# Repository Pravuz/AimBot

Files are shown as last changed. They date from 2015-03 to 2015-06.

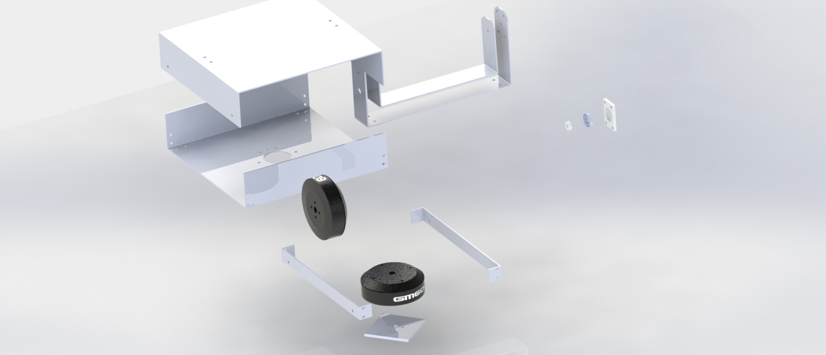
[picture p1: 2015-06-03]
3D model/Rendered images/Overview parts.JPG

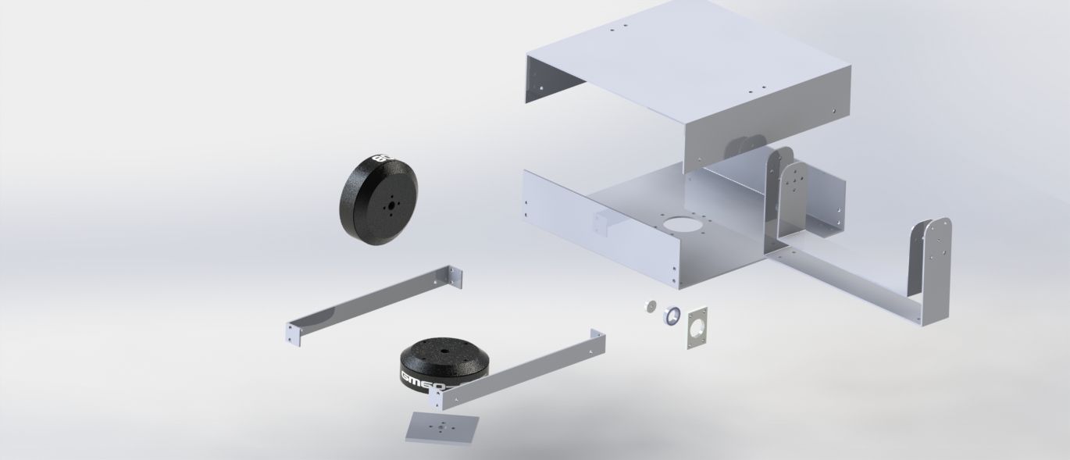
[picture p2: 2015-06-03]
3D model/Rendered images/Overview parts 2.JPG

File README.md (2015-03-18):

# AimBot
<i>Undergrad Robotics project. Check out our youtube (www.youtube.com/channel/UCTwyZwKfavoUkVI_xjq9n3A) if you're interested.
This is a Bachelors project on constructing an automated camera-rig.</i><br /><br />

<h2>Folder contents:</h2>

<h3>Arduino:</h3> Arduino mega 2560, the "brain" of the rig <br />
<h3>Brugi:</h3> Brushless DC-motor controller, based on Sine-wave pwm on 2-axis. <br />
<h3>Common:</h3> Files that all source code implements. protocols etc.<br />
<h3>Desktop:</h3> Windows configuration program <br />
<h3>Pixy:</h3> Camera module with a dual-core arm cpu for image processing.<br />
<h3>Release:</h3> Executable's etc for end-user.<br />

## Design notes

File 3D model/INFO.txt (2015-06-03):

INFO:
-------------------------
This folder contains 3D models created in SolidWorks, as well as
rendered images.

Folders:
-------------------------
- 'Assembly 13 - 2 axis' 
	Contains the 3D model of the 2axis-rig
	The full assembly is located at: 
		'/3D model/Assembly 13 - 2 axis/Assembly/Assem2.SLDASM'

- 'Assembly 14 - 3 axis' 
	Contains the 3D model of the 3axis-rig
	The full assembly is located at: 
		'/3D model/Assembly 14 - 3 axis/Assembly/Assem2.SLDASM'

- 'Rendered images'
	Contains rendered images

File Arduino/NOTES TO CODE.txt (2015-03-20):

--------timepassed and oldtime --------------------------------
// max value for 16bit int = 32767
// 32 767us = 0,032767s og 1/0,032767s=30,51850947599719hz
// max value for 16bit uint = 65535
// could change timepassed to a 16bit uint
// oldtime however gets huge, needs long

--------interrupts  --------------------------------
// Interrupt pins on mega:
// int.0 = 2, int.1 = 3, int.2 = 21, int.3 = 20, int.4 = 19, int.5 = 18

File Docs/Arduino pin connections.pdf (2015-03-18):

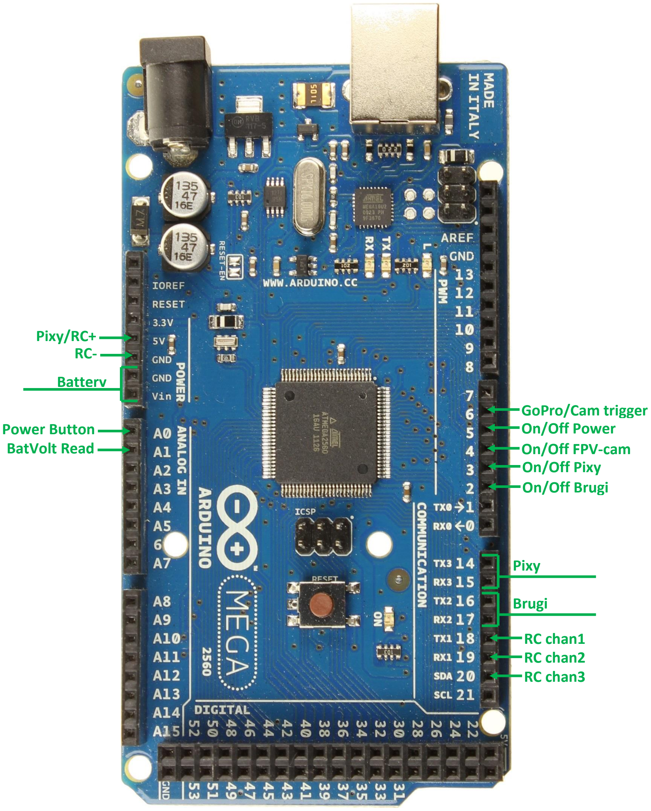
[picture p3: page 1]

Pixy

Brugi

BatVolt Read

Power

Button

RC chan1
RC chan2
RC chan3

On/Off Pixy

On/Off FPV

-cam

On/Off Brugi

On/Off Power

Battery

Pixy/RC+
RC

GoPro/Cam trigger

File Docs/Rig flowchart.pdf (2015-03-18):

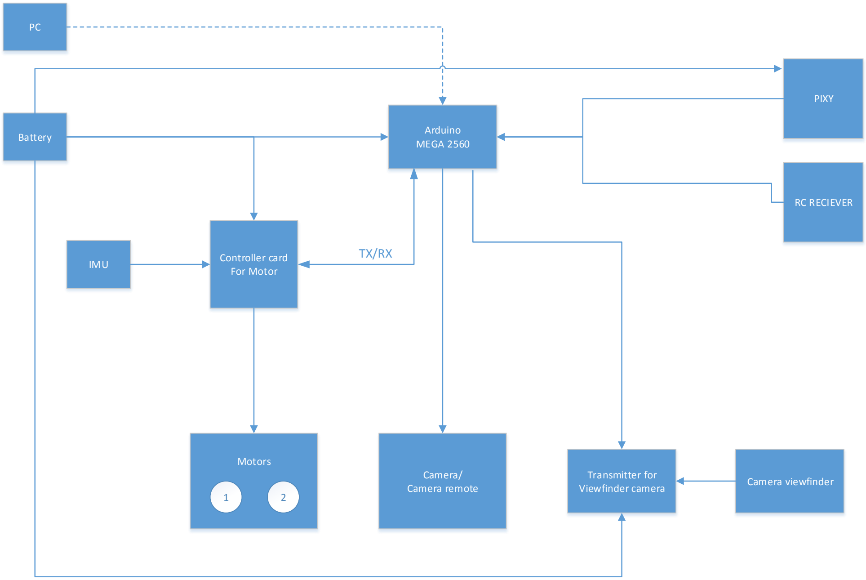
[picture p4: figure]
Arduino MEGA 2560; PIXY; RC RECIEVER; Battery; Controller card For Motor IMU; Transmitter for; Viewfinder camera; Camera viewfinder; Motors; Camera/ Camera remote

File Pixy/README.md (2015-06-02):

<h1>Pixy</h1>
</br>
<b>Q:</b> Where does the magic happen?</br>
<b>A:</b> In the GreyShades class (pixy/gcc/video/proggreyshades.h\cpp)</br>
</br>
<b>Q:</b> How does it work?</br>
<b>A:</b> GreyShades attempts to identify moving objects by tracking changes in individual pixel values (luminosity). </br>Because of certain limitations, the filtering of objects is quite rough however. </br>
</br>
<b>Q:</b> Why is it called greyshades?</br>
<b>A:</b> Because it's not based on colors, but shades of grey ( sizeOf(uint8_t)-1 different shades in fact).</br>
</br>
<b>Q:</b> What else can this firmware do?</br>
<b>A:</b> Not much. This firmware is based on an early pre-alpha gcc build by CharmedLabs, stripped down to rule out potential </br>crashes/resource usage/bugs.</br>
</br>
<b>Q:</b> Will this firmware work on my Pixy?</br>
<b>A:</b> Maybe, I'm not certain Pixymon will allow flashing your pixy with the .hex generated by this code. I used a</br> debugger (LPC-Link2) to test and upload the firmware. </br>
</br>
<b>Q:</b> Is this currently a work in progress?</br>
<b>A:</b> This project was part of a bachelor's project, which is now finished. The source code found here will remain as is, </br>with no guarantee or promises with it. </br>
</br>
<b>Q:</b> Can I use your code as I please?</br>
<b>A:</b> Yes, by all means! Some credit would be nice however :)</br>
</br>
<b>Q:</b> Can I contact you?</br>
<b>A:</b> Yes, preferably via github (I'm Pravuz). I'm not promising any reply, as I'm quite busy nowadays. </br>
</br></br></br>
- Pravuz

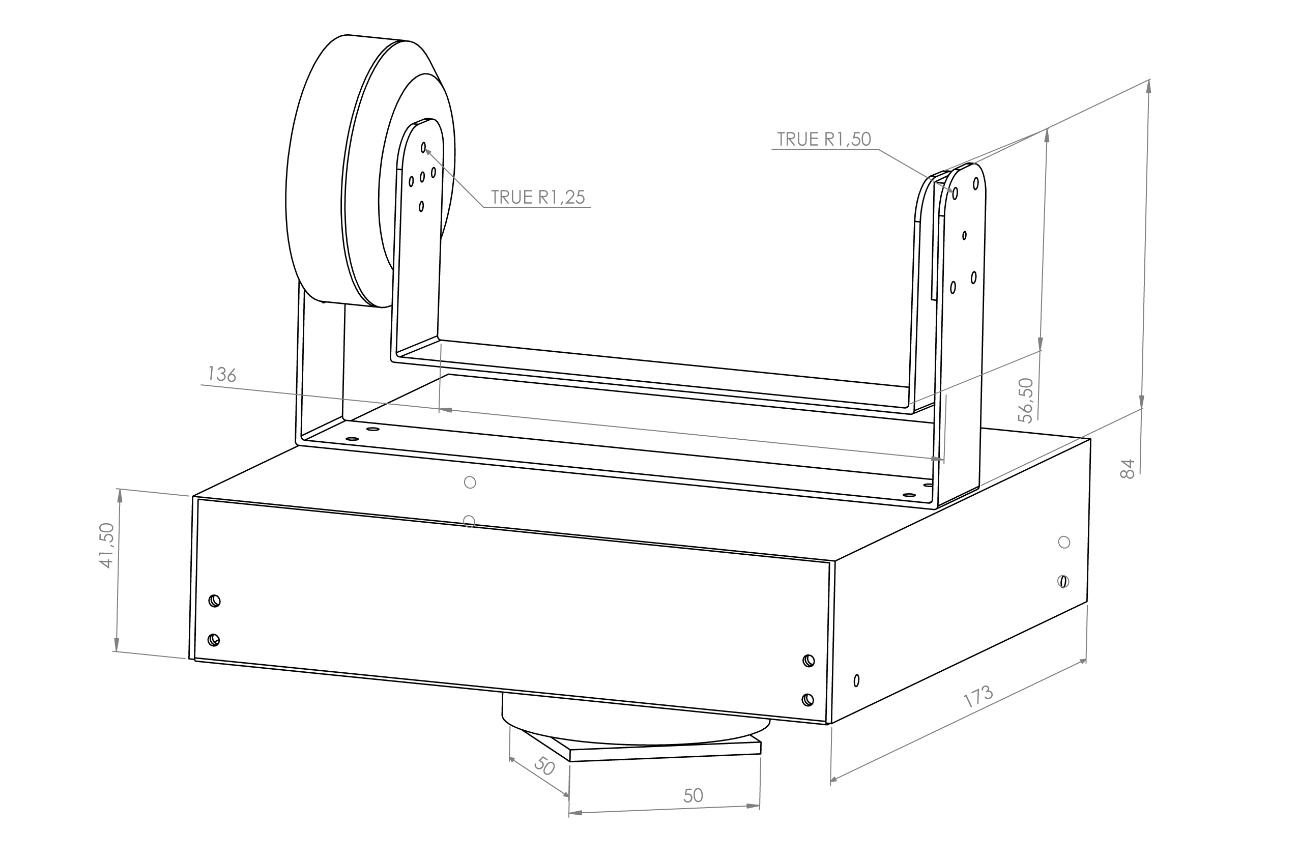
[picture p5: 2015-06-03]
3D model/Rendered images/Schematic view.PNG

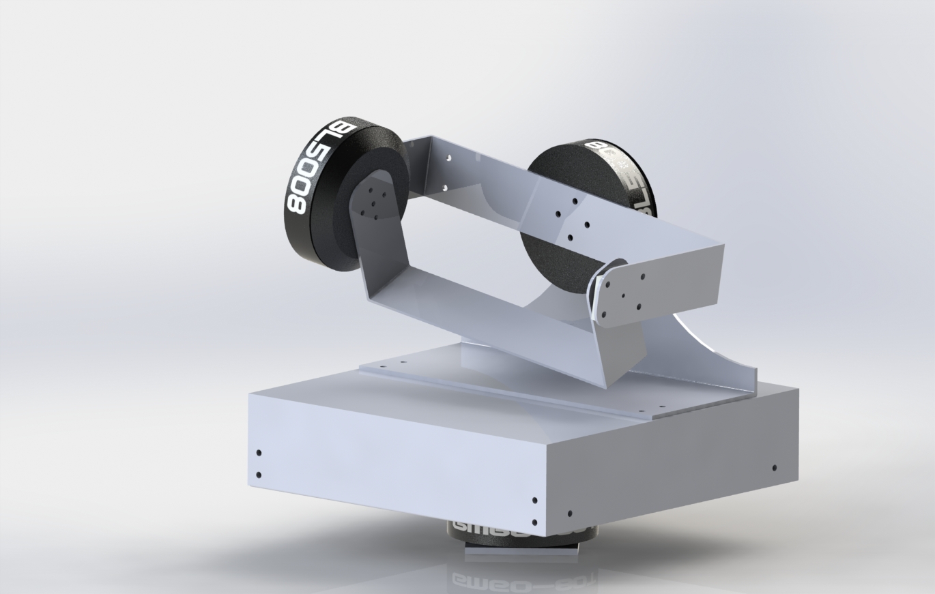
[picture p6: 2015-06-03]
3D model/Rendered images/Front view 3rd axis.JPG

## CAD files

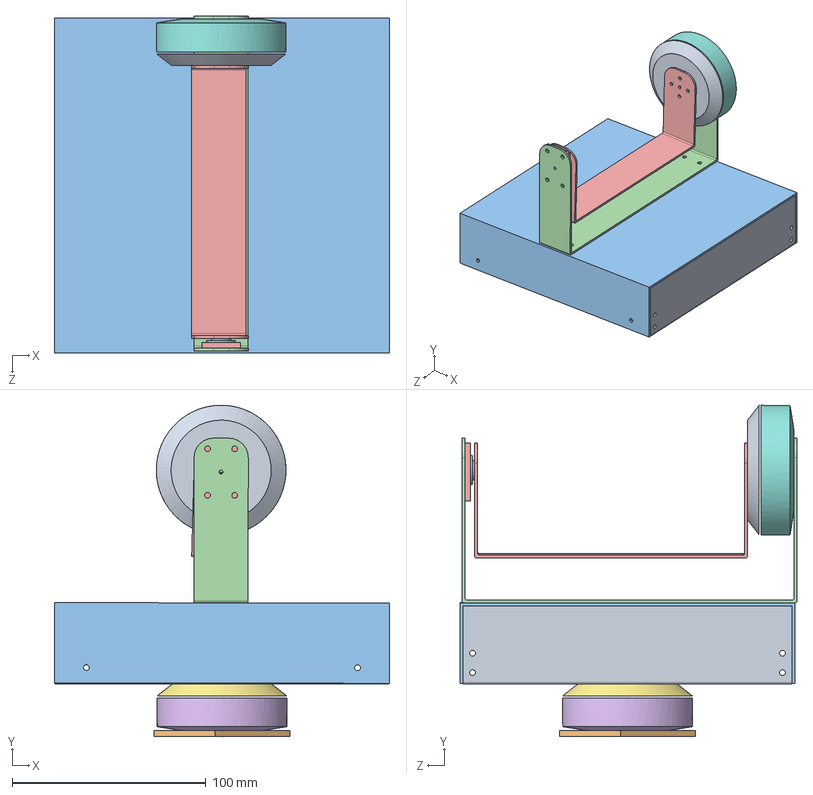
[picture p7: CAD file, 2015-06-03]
3D model/Assembly 13 - 2 axis/Assembly/Assem2.SLDASM
173.0 x 171.2 x 174.0 mm
Bunnplate til boks
side-L x 2
topplate
midtre L 1
øvre L
Motorbunn
Motortopp
Motorbunnøvre
Motortoppøvre
tripod montasjeplate
Indre holder
Kulelager
Ytre holder

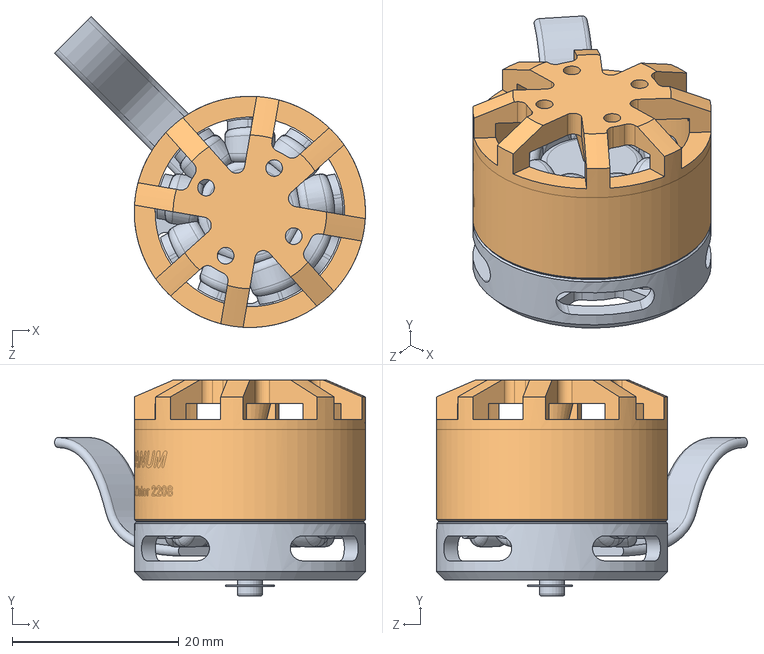
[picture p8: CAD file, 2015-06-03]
3D model/Assembly 13 - 2 axis/quanum-motor-2208-1.snapshot.4/QUANUM GIMBAL MOTOR 2208 ASM.SLDASM
37.3 x 25.9 x 37.3 mm
QUANUM GIMBAL MOTOR 2208 BASE
QUANUM GIMBAL MOTOR 2208 OUTRUNNER

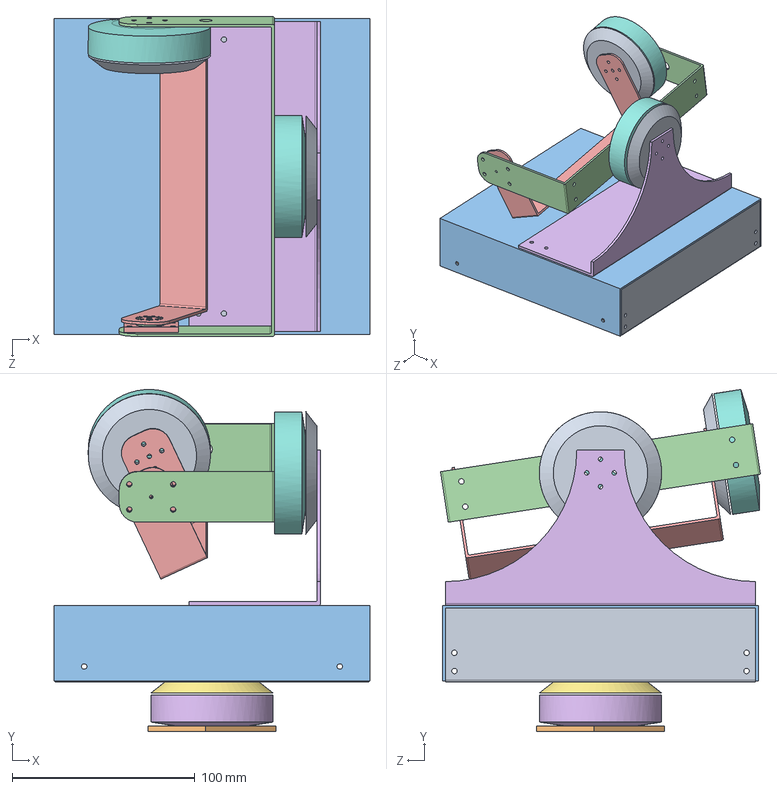
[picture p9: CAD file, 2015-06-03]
3D model/Assembly 14 - 3 axis/Assembly/Assem2.SLDASM
173.0 x 187.3 x 175.2 mm
Bunnplate til boks
side-L x 2
topplate
midtre L 1
øvre L
Motorbunn
Motortopp
Motorbunnøvre x 2
Motortoppøvre x 2
tripod montasjeplate
Indre holder
Kulelager
Ytre holder
platebøy-akse3

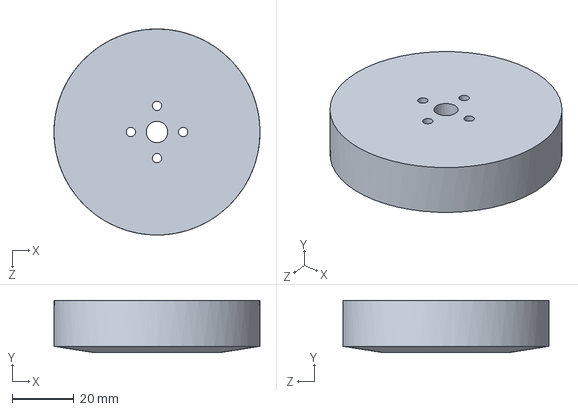
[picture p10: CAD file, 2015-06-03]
3D model/Assembly 13 - 2 axis/GM60-80T - øvre motor/Motorbunnøvre.SLDPRT
67.0 x 17.0 x 67.0 mm

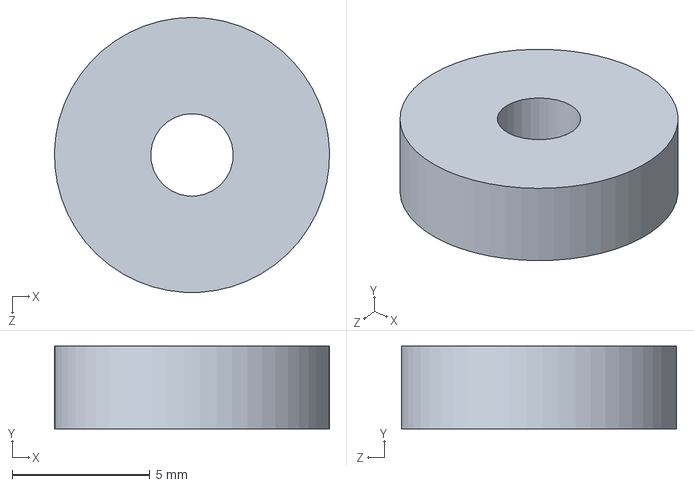
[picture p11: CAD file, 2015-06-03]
3D model/Assembly 13 - 2 axis/Kulelager/Indre holder.SLDPRT
10.00 x 3.00 x 10.0 mm

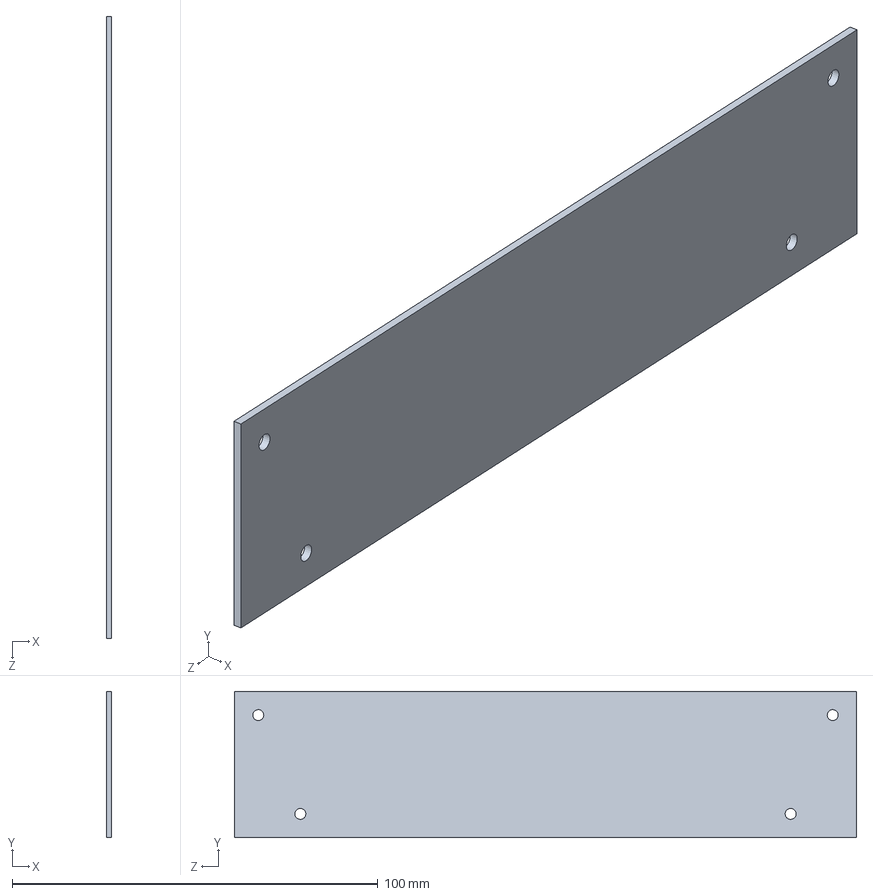
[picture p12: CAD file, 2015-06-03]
3D model/Assembly 13 - 2 axis/Parts/vegger side 2.SLDPRT
1.50 x 40.0 x 170.0 mm

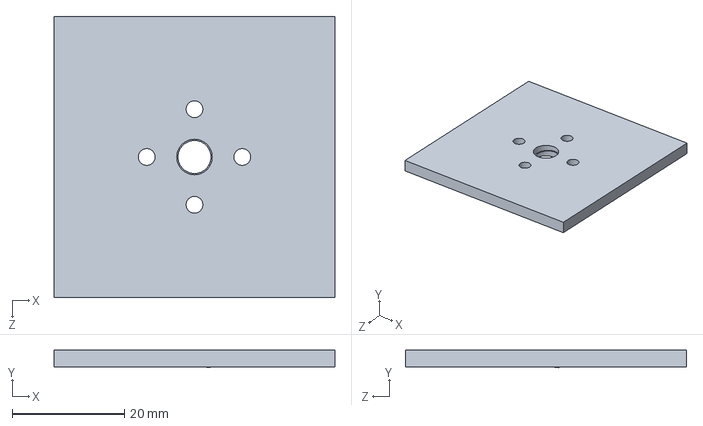
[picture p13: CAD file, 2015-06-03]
3D model/Assembly 13 - 2 axis/Tripod montasjeplate/tripod montasjeplate.SLDPRT
50.0 x 3.12 x 50.0 mm

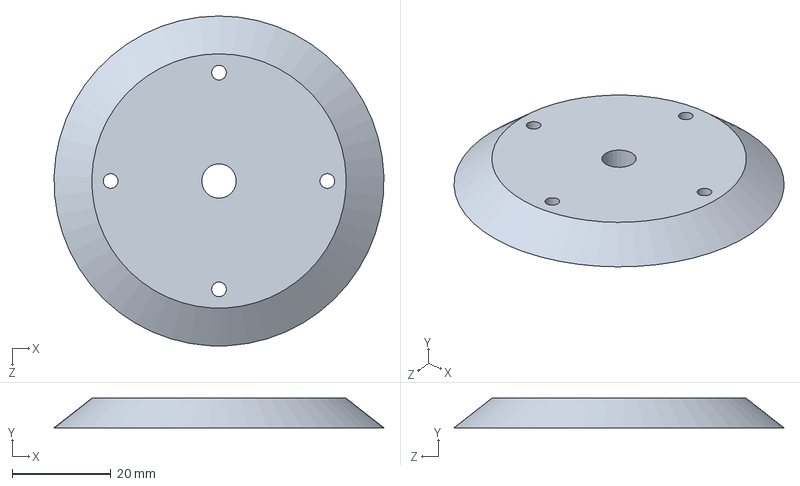
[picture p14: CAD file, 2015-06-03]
3D model/Assembly 14 - 3 axis/GM60-80T/Motortopp.SLDPRT
67.0 x 6.00 x 67.0 mm

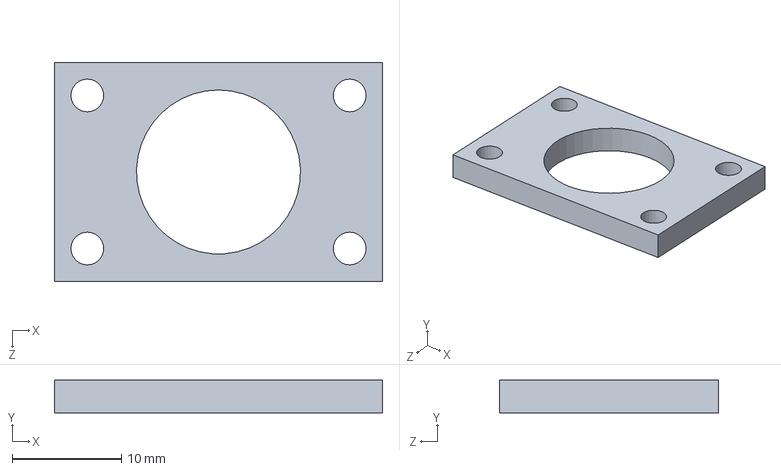
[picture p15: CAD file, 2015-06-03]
3D model/Assembly 14 - 3 axis/Kulelager/Ytre holder.SLDPRT
30.0 x 3.00 x 20.0 mm

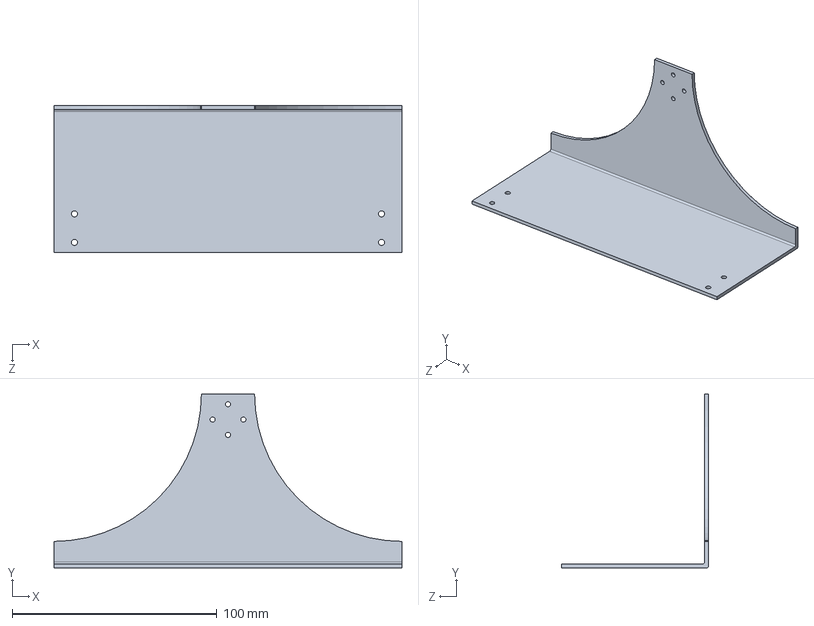
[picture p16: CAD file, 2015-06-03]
3D model/Assembly 14 - 3 axis/platebøy-akse3/platebøy-akse3.SLDPRT
170.0 x 85.0 x 72.0 mm

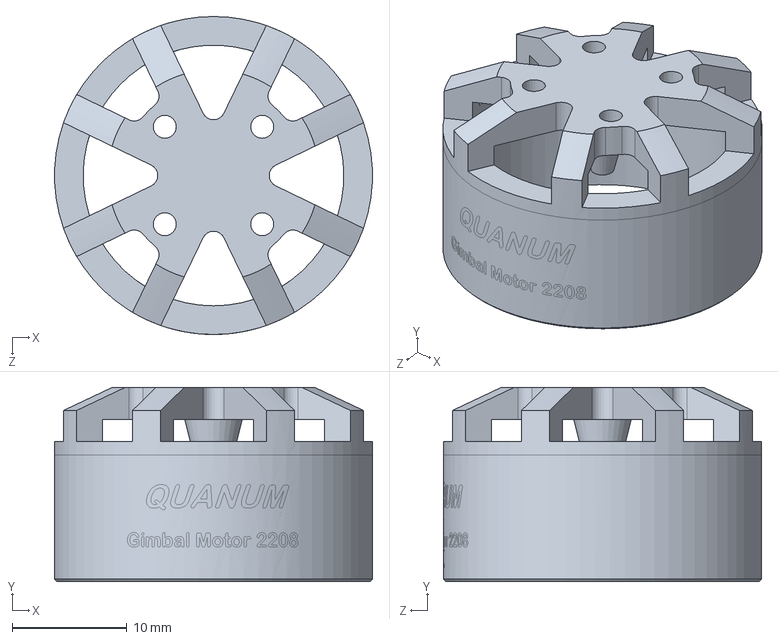
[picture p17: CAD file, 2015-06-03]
3D model/Assembly 14 - 3 axis/quanum-motor-2208-1.snapshot.4/QUANUM GIMBAL MOTOR 2208 OUTRUNNER.SLDPRT
27.7 x 16.9 x 27.7 mm

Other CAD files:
3D model/Assembly 13 - 2 axis/GM60-80T/GM60-80t assembly.SLDASM
3D model/Assembly 14 - 3 axis/GM60-80T - øvre motor/GM60-80t assembly.SLDASM
3D model/Assembly 14 - 3 axis/GM60-80T/GM60-80t assembly.SLDASM
3D model/Assembly 13 - 2 axis/GM60-80T - øvre motor/GM60-80t assembly.SLDASM
3D model/Assembly 14 - 3 axis/Parts/Nederste bunnplate.SLDPRT
3D model/Assembly 13 - 2 axis/GM60-80T - øvre motor/Motortoppøvre.SLDPRT
3D model/Assembly 13 - 2 axis/GM60-80T/Motorbunn.SLDPRT
3D model/Assembly 13 - 2 axis/Kulelager/Kulelager.SLDPRT
3D model/Assembly 13 - 2 axis/Parts/5mm motorholder.SLDPRT
3D model/Assembly 13 - 2 axis/Parts/Bunnplate til boks.SLDPRT
3D model/Assembly 13 - 2 axis/Parts/L-jern til boks.SLDPRT
3D model/Assembly 13 - 2 axis/Parts/Nederste bunnplate.SLDPRT
3D model/Assembly 13 - 2 axis/Parts/midtre L 1.SLDPRT
3D model/Assembly 13 - 2 axis/Parts/side-L.SLDPRT
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

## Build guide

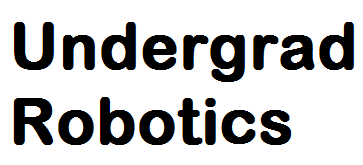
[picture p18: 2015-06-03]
3D model/Assembly 13 - 2 axis/GM60-80T - øvre motor/UR decal.png

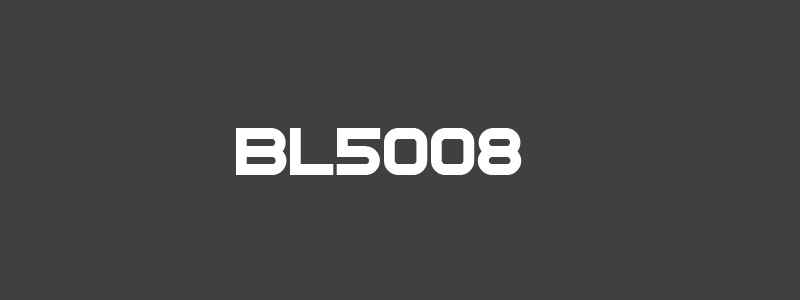
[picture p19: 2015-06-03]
3D model/Assembly 14 - 3 axis/GM60-80T - øvre motor/bl5008decal.png

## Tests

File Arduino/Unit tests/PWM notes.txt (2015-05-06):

sjekk GEAR på monitor, at det funker aux er mode select!

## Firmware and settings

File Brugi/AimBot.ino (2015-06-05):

#include "BLcontroller.h"
#include "Interupts_.h"
#include <Wire\Wire.h>
#define __ESC
#include "Aimbot_Serial.h"

#define bldc1 0.2008929 //360degree/256sinval/7magneticpos
#define bldc2 0.1278409 //360/256/11
#define DIR_MASK 0x80
#define Y_MIN_LIMIT -160
#define Y_MAX_LIMIT 320
#define MOTORPOWER 255 // 0 to 255
#define MOTOR_0_DEFAULT_FREQ 128
#define MOTOR_1_DEFAULT_FREQ 64
#define MOTOR_0_MIN_FREQ 192
#define MOTOR_1_MIN_FREQ 96
#define MOTOR_0_MAX_FREQ 256
#define MOTOR_1_MAX_FREQ 256
#define SPEED_FACTOR_Z 9
#define SPEED_FACTOR_Y 20
int speedCountY = 0; // RC mode counters for speed factor
int speedCountZ = 0;

char z_Pos = 0, y_Pos = 0;
int16_t z_Pos_Steps = 0, y_Pos_Steps = 0, y_Motor_Signed = 0;
uint8_t z_Motor = 0, y_Motor = 0;
bool rc_mode = false;

static AimBot_Serial megaSerial(Serial);

void setup()
{
	Serial.begin(BAUDRATE);

	initBlController();

	initMotorStuff();

	motorPowerOff();
	
	//sei();

#if 1
	//moving to 0 pos. 
	MoveMotorPosSpeed(motorNumberYaw, y_Motor, 100);
	MoveMotorPosSpeed(motorNumberPitch, z_Motor, 100);
	delay(150);
	megaSerial.sendPosReached();
#endif

	motor_0_freq = MOTOR_0_DEFAULT_FREQ;
	motor_1_freq = MOTOR_1_DEFAULT_FREQ;
}

void loop()
{
#if 1
	if (megaSerial.update())
	{
		rc_mode = megaSerial.isRCmode();
		z_Pos = megaSerial.getX();
		y_Pos = megaSerial.getY();

		if (!rc_mode) moveToPos();
		else 
		{
			motor_0_freq = MOTOR_0_DEFAULT_FREQ;
			motor_1_freq = MOTOR_1_DEFAULT_FREQ;
			//setMotorFreqRC(z_Pos, motorNumberPitch);
			//setMotorFreqRC(y_Pos, motorNumberYaw);
			//motor_0_freq = MOTOR_0_MIN_FREQ;
			//motor_1_freq = MOTOR_1_MIN_FREQ;
		}
		megaSerial.flush();
	}
	//when in RC-mode, we want to continually move regardless of the success of serial update. 
	if (rc_mode) moveWithSpeed();
	else
	{
		MoveMotorPosSpeed(motorNumberYaw, y_Motor, 100);
		MoveMotorPosSpeed(motorNumberPitch, z_Motor, 100);
	}
#endif
#if 0
	if (motor_0_update) {
		motor_0_update = false;
		z_Motor++;
		MoveMotorPosSpeed(motorNumberPitch, z_Motor, 255);
		if(!z_Motor) delay(500000);
	}
#endif
}

void moveToPos()
{

	//converting angle to motor steps.
	z_Pos_Steps = z_Pos / bldc2;
	y_Pos_Steps = y_Pos / bldc1;

	int16_t z_pos_origin = z_Pos_Steps;
	int16_t y_pos_origin = y_Pos_Steps;

	while ((z_Pos_Steps != 0) || (y_Pos_Steps != 0))
	{
		if (motor_0_update && z_Pos_Steps != 0)
		{
			if (z_Pos_Steps > 0)
			{
				--z_Pos_Steps;
				--z_Motor;
			}
			else if (z_Pos_Steps < 0)
			{
				++z_Pos_Steps;
				++z_Motor;
			}
			setMotorFreq(z_pos_origin, z_Pos_Steps, motorNumberPitch);
			motor_0_update = false;
			MoveMotorPosSpeed(motorNumberPitch, z_Motor, MOTORPOWER);
		}
		if (motor_1_update && y_Pos_Steps != 0)
		{
			if (y_Pos_Steps > 0)
			{
				if (y_Motor_Signed > Y_MIN_LIMIT){
					y_Motor--;
					y_Motor_Signed--;
					y_Pos_Steps--;
				}
				else y_Pos_Steps = 0;
			}
			else if (y_Pos_Steps < 0)
			{
				if (y_Motor_Signed < Y_MAX_LIMIT){
					y_Motor++;
					y_Motor_Signed++;
					y_Pos_Steps++;
				}
				else y_Pos_Steps = 0;
			}
			setMotorFreq(y_pos_origin, y_Pos_Steps, motorNumberYaw);
			motor_1_update = false;
			MoveMotorPosSpeed(motorNumberYaw, y_Motor, MOTORPOWER);
		}
	}
	//delay(100); //wait for rig to settle a little
	megaSerial.sendPosReached();
}


void moveWithSpeed()
{

	if ((z_Pos >= -1 && z_Pos <= 1)) z_Pos = 0;
	if ((y_Pos >= -1 && y_Pos <= 1)) y_Pos = 0;

	if (motor_0_update){
		motor_0_update = false;
		speedCountZ += abs(z_Pos);
		if (speedCountZ > SPEED_FACTOR_Z)
		{
			speedCountZ = 0;
			if (z_Pos & DIR_MASK) z_Motor--;
			else if (z_Pos) z_Motor++;
		}
		MoveMotorPosSpeed(motorNumberPitch, z_Motor, MOTORPOWER);
	}

	if (motor_1_update){
		motor_1_update = false;
		speedCountY += abs(y_Pos);
		if (speedCountY > SPEED_FACTOR_Y)
		{
			speedCountY = 0;
			if ((y_Pos & DIR_MASK) && y_Motor_Signed > Y_MIN_LIMIT){
				y_Motor--;
				y_Motor_Signed--;
			}
			else if (y_Pos && y_Motor_Signed < Y_MAX_LIMIT){
				y_Motor++;
				y_Motor_Signed++;
			}
		}
		MoveMotorPosSpeed(motorNumberYaw, y_Motor, MOTORPOWER);
	}

#if 0
	if (motor_0_update)
	{
		motor_0_update = false;
		speedCountZ += z_Pos;
		if (speedCountZ > 40)
		{
			MoveMotorPosSpeed(motorNumberPitch, z_Motor++, MOTORPOWER);
			speedCountZ = 0;
		}
	}
	if (motor_1_update)
	{
		motor_1_update = false;	
		speedCountY += y_Pos;
		if (speedCountY > 40)
		{
			MoveMotorPosSpeed(motorNumberYaw, y_Motor++, MOTORPOWER);
			speedCountY = 0;
		}
	}
#endif
}

void setMotorFreq(int16_t &origin, int16_t &progress, uint8_t motorNumber)
{
	switch (motorNumber)
	{
	case motorNumberPitch:
		if ((origin/2)<progress) motor_0_freq = origin > 0 ? map(progress, 0, origin, MOTOR_0_MAX_FREQ, MOTOR_0_MIN_FREQ) : map(progress, origin, 0, MOTOR_0_MAX_FREQ, MOTOR_0_MIN_FREQ);
		else motor_0_freq = origin > 0 ? map(progress, 0, origin, MOTOR_0_MIN_FREQ, MOTOR_0_MAX_FREQ) : map(progress, origin, 0, MOTOR_0_MIN_FREQ, MOTOR_0_MAX_FREQ);
		break;
	case motorNumberYaw:
		if ((origin/2)<progress) motor_1_freq = origin > 0 ? map(progress, 0, origin, MOTOR_1_MAX_FREQ, MOTOR_1_MIN_FREQ) : map(progress, origin, 0, MOTOR_1_MAX_FREQ, MOTOR_1_MIN_FREQ);
		else motor_1_freq = origin > 0 ? map(progress, 0, origin, MOTOR_1_MIN_FREQ, MOTOR_1_MAX_FREQ) : map(progress, origin, 0, MOTOR_1_MIN_FREQ, MOTOR_1_MAX_FREQ);
		break;
	default:
		break;
	}
}

void setMotorFreqRC(int RCval, uint8_t motorNumber)
{
	RCval = abs(RCval);
	switch (motorNumber)
	{
	case motorNumberPitch:
		motor_0_freq = map(RCval, 0, 10, MOTOR_0_MIN_FREQ, MOTOR_0_MAX_FREQ);
		break;
	case motorNumberYaw:
		motor_1_freq = map(RCval, 0, 10, MOTOR_1_MIN_FREQ, MOTOR_1_MAX_FREQ);
		break;
	default:
		break;
	}
}
	

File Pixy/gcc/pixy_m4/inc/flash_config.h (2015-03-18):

/*
 * @brief SPIFI Flash configuration header file
 *
 * @note
 * Copyright(C) NXP Semiconductors, 2012
 * All rights reserved.
 *
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
 * @par
 * Permission to use, copy, modify, and distribute this software and its
 * documentation is hereby granted, under NXP Semiconductors' and its
 * licensor's relevant copyrights in the software, without fee, provided that it
 * is used in conjunction with NXP Semiconductors microcontrollers.  This
 * copyright, permission, and disclaimer notice must appear in all copies of
 * this code.
 */
 
#ifndef __FLASH_CONFIG_H_
#define __FLASH_CONFIG_H_

/** @ingroup EXAMPLES_MISC_18XX43XX_SPIFI_PROGRAMMER
 * @{
 */

/** @def USE_SPIFI_LIB
 * Macro that enables calling of spifi functions using the library,
 * disabling this will directly call the functions in boot rom using
 * bootROM function pointers.
 */
#define USE_SPIFI_LIB

//#include "board.h"
#include "spifi_rom_api.h"

// For LPC 1830/4330 nXplorer board
#define SPIFLASH_DEVICE_SIZE        (4 * 1024 * 1024)
#define SPIFLASH_SECTOR_SIZE        (64 * 1024)
#define SPIFLASH_NUM_OF_SECTORS     (SPIFLASH_DEVICE_SIZE/SPIFLASH_SECTOR_SIZE)
#define SPIFLASH_BASE_ADDRESS       0x14000000


/** @def SPIFI_WRITE_SECTOR_OFFSET
 * Offset of the sector to which the data to be written
 */
#define SPIFI_WRITE_SECTOR_OFFSET       0x40000
#define SPIFI_WRITE_SECTOR_ADDRESS      (SPIFLASH_BASE_ADDRESS + SPIFI_WRITE_SECTOR_OFFSET)

#define spifi_rom_init(x)

#ifndef USE_SPIFI_LIB
#define spifi_init                       spifi->spifi_init
#define spifi_program                    spifi->spifi_program
#undef  spifi_rom_init
#define spifi_rom_init(x)                define_spifi_romPtr(x)
#endif

/**
 * @}
 */

#endif /* ifndef __FLASH_CONFIG_H_ */

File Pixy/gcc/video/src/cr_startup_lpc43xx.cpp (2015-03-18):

//*****************************************************************************
// LPC43xx (Cortex-M4) Microcontroller Startup code for use with LPCXpresso IDE
//
// Version : 140113
//*****************************************************************************
//
// Copyright(C) NXP Semiconductors, 2013-2014
// All rights reserved.
//
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
// Permission to use, copy, modify, and distribute this software and its
// documentation is hereby granted, under NXP Semiconductors' and its
// licensor's relevant copyrights in the software, without fee, provided that it
// is used in conjunction with NXP Semiconductors microcontrollers.  This
// copyright, permission, and disclaimer notice must appear in all copies of
// this code.
//*****************************************************************************

#if defined (__cplusplus)
#ifdef __REDLIB__
#error Redlib does not support C++
#else
//*****************************************************************************
//
// The entry point for the C++ library startup
//
//*****************************************************************************
extern "C" {
    extern void __libc_init_array(void);
}
#endif
#endif

#define WEAK __attribute__ ((weak))
#define ALIAS(f) __attribute__ ((weak, alias (#f)))

//*****************************************************************************
#if defined (__cplusplus)
extern "C" {
#endif

//*****************************************************************************
#if defined (__USE_CMSIS) || defined (__USE_LPCOPEN)
// Declaration of external SystemInit function
extern void SystemInit(void);
#endif

//*****************************************************************************
//
// Forward declaration of the default handlers. These are aliased.
// When the application defines a handler (with the same name), this will 
// automatically take precedence over these weak definitions
//
//*****************************************************************************
void ResetISR(void);
WEAK void NMI_Handler(void);
WEAK void HardFault_Handler(void);
WEAK void MemManage_Handler(void);
WEAK void BusFault_Handler(void);
WEAK void UsageFault_Handler(void);
WEAK void SVC_Handler(void);
WEAK void DebugMon_Handler(void);
WEAK void PendSV_Handler(void);
WEAK void SysTick_Handler(void);
WEAK void IntDefaultHandler(void);

//*****************************************************************************
//
// Forward declaration of the specific IRQ handlers. These are aliased
// to the IntDefaultHandler, which is a 'forever' loop. When the application
// defines a handler (with the same name), this will automatically take 
// precedence over these weak definitions
//
//*****************************************************************************
void DAC_IRQHandler(void) ALIAS(IntDefaultHandler);
#if defined (__USE_LPCOPEN)
void MX_CORE_IRQHandler(void) ALIAS(IntDefaultHandler);
#else
void M0CORE_IRQHandler(void) ALIAS(IntDefaultHandler);
#endif
void DMA_IRQHandler(void) ALIAS(IntDefaultHandler);
#if defined (__USE_LPCOPEN)
void FLASHEEPROM_IRQHandler(void) ALIAS(IntDefaultHandler);
#else
void FLASH_EEPROM_IRQHandler(void) ALIAS(IntDefaultHandler);
#endif
void ETH_IRQHandler(void) ALIAS(IntDefaultHandler);
void SDIO_IRQHandler(void) ALIAS(IntDefaultHandler);
void LCD_IRQHandler(void) ALIAS(IntDefaultHandler);
void USB0_IRQHandler(void) ALIAS(IntDefaultHandler);
void USB1_IRQHandler(void) ALIAS(IntDefaultHandler);
void SCT_IRQHandler(void) ALIAS(IntDefaultHandler);
void RIT_IRQHandler(void) ALIAS(IntDefaultHandler);
void TIMER0_IRQHandler(void) ALIAS(IntDefaultHandler);
void TIMER1_IRQHandler(void) ALIAS(IntDefaultHandler);
void TIMER2_IRQHandler(void) ALIAS(IntDefaultHandler);
void TIMER3_IRQHandler(void) ALIAS(IntDefaultHandler);
void MCPWM_IRQHandler(void) ALIAS(IntDefaultHandler);
void ADC0_IRQHandler(void) ALIAS(IntDefaultHandler);
void I2C0_IRQHandler(void) ALIAS(IntDefaultHandler);
void SPI_IRQHandler(void) ALIAS(IntDefaultHandler);
void I2C1_IRQHandler(void) ALIAS(IntDefaultHandler);
void ADC1_IRQHandler(void) ALIAS(IntDefaultHandler);
void SSP0_IRQHandler(void) ALIAS(IntDefaultHandler);
void SSP1_IRQHandler(void) ALIAS(IntDefaultHandler);
void UART0_IRQHandler(void) ALIAS(IntDefaultHandler);
void UART1_IRQHandler(void) ALIAS(IntDefaultHandler);
void UART2_IRQHandler(void) ALIAS(IntDefaultHandler);
void UART3_IRQHandler(void) ALIAS(IntDefaultHandler);
void I2S0_IRQHandler(void) ALIAS(IntDefaultHandler);
void I2S1_IRQHandler(void) ALIAS(IntDefaultHandler);
void SPIFI_IRQHandler(void) ALIAS(IntDefaultHandler);
void SGPIO_IRQHandler(void) ALIAS(IntDefaultHandler);
void GPIO0_IRQHandler(void) ALIAS(IntDefaultHandler);
void GPIO1_IRQHandler(void) ALIAS(IntDefaultHandler);
void GPIO2_IRQHandler(void) ALIAS(IntDefaultHandler);
void GPIO3_IRQHandler(void) ALIAS(IntDefaultHandler);
void GPIO4_IRQHandler(void) ALIAS(IntDefaultHandler);
void GPIO5_IRQHandler(void) ALIAS(IntDefaultHandler);
void GPIO6_IRQHandler(void) ALIAS(IntDefaultHandler);
void GPIO7_IRQHandler(void) ALIAS(IntDefaultHandler);
void GINT0_IRQHandler(void) ALIAS(IntDefaultHandler);
void GINT1_IRQHandler(void) ALIAS(IntDefaultHandler);
void EVRT_IRQHandler(void) ALIAS(IntDefaultHandler);
void CAN1_IRQHandler(void) ALIAS(IntDefaultHandler);
#if defined (__USE_LPCOPEN)
void ADCHS_IRQHandler(void) ALIAS(IntDefaultHandler);
#else
void VADC_IRQHandler(void) ALIAS(IntDefaultHandler);
#endif
void ATIMER_IRQHandler(void) ALIAS(IntDefaultHandler);
void RTC_IRQHandler(void) ALIAS(IntDefaultHandler);
void WDT_IRQHandler(void) ALIAS(IntDefaultHandler);
void M0SUB_IRQHandler(void) ALIAS(IntDefaultHandler);
void CAN0_IRQHandler(void) ALIAS(IntDefaultHandler);
void QEI_IRQHandler(void) ALIAS(IntDefaultHandler);

//*****************************************************************************
//
// The entry point for the application.
// __main() is the entry point for Redlib based applications
// main() is the entry point for Newlib based applications
//
//*****************************************************************************
#if defined (__REDLIB__)
extern void __main(void);
#endif
extern int main(void);
//*****************************************************************************
//
// External declaration for the pointer to the stack top from the Linker Script
//
//*****************************************************************************
extern void _vStackTop(void);
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

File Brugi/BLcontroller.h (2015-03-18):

#include <Arduino.h>
#include "definitions.h"


/*Initialize motorcontroller
Setter pinner og velger frekvens*/
void initBlController()
{
	pinMode(3, OUTPUT);
	pinMode(5, OUTPUT);
	pinMode(6, OUTPUT);
	pinMode(9, OUTPUT);
	pinMode(10, OUTPUT);
	pinMode(11, OUTPUT);

#ifdef PWM_8KHZ_FAST
	TCCR0A = _BV(COM0A1) | _BV(COM0B1) | _BV(WGM01) | _BV(WGM10);
	TCCR0B = _BV(CS01);
	TCCR1A = _BV(COM0A1) | _BV(COM0B1) | _BV(WGM10);
	TCCR1B = _BV(WGM12) | _BV(CS11);
	TCCR2A = _BV(COM0A1) | _BV(COM0B1) | _BV(WGM21) | _BV(WGM20);
	TCCR2B = _BV(CS21);
#endif

#ifdef PWM_32KHZ_PHASE
	TCCR0A = _BV(COM0A1) | _BV(COM0B1) | _BV(WGM00);
	TCCR0B = _BV(CS00);
	TCCR1A = _BV(COM1A1) | _BV(COM1B1) | _BV(WGM10);
	TCCR1B = _BV(CS10);
	TCCR2A = _BV(COM2A1) | _BV(COM2B1) | _BV(WGM20);
	TCCR2B = _BV(CS20);
#endif

#ifdef PWM_4KHZ_PHASE
	TCCR0A = _BV(COM0A1) | _BV(COM0B1) | _BV(WGM00);
	TCCR0B = _BV(CS01);
	TCCR1A = _BV(COM1A1) | _BV(COM1B1) | _BV(WGM10);
	TCCR1B = _BV(CS11);
	TCCR2A = _BV(COM2A1) | _BV(COM2B1) | _BV(WGM20);
	TCCR2B = _BV(CS21);
#endif

	// enable Timer 1 interrupt
	TIMSK1 |= _BV(TOIE1);

	// disable arduino standard timer interrupt
	TIMSK0 &= ~_BV(TOIE1);

	sei();

	// Enable Timer1 Interrupt for Motor Control
	OCR2A = 0;  //11  APIN
	OCR2B = 0;  //D3
	OCR1A = 0;  //D9  CPIN
	OCR1B = 0;  //D10 BPIN
	OCR0A = 0;  //D6
	OCR0B = 0;  //D5 
}

void calcSinusArray()
{
	for (int i = 0; i<N_SIN; i++)
	{
		pwmSinMotor[i] = sin(2.0 * i / N_SIN * 3.14159265) * 127.0;
	}
}

void initMotorStuff()
{
	cli();
	calcSinusArray();
	sei();
}

void MoveMotorPosSpeed(uint8_t motorNumber, int MotorPos, uint16_t maxPWM)
{
	uint16_t posStep;
	int16_t pwm_a;
	int16_t pwm_b;
	int16_t pwm_c;

	// fetch pwm from sinus table
	posStep = MotorPos & 0xff;
	pwm_a = pwmSinMotor[(uint8_t)posStep];
	pwm_b = pwmSinMotor[(uint8_t)(posStep + 85)];
	pwm_c = pwmSinMotor[(uint8_t)(posStep + 170)];

	// apply power factor
	
	pwm_a = maxPWM * pwm_a;
	pwm_a = pwm_a >> 8;
	pwm_a += 128;
		
	pwm_b = maxPWM * pwm_b;
	pwm_b = pwm_b >> 8;
	pwm_b += 128;
		
	pwm_c = maxPWM * pwm_c;
	pwm_c = pwm_c >> 8;
	pwm_c += 128;




	// set motor pwm variables
	if (motorNumber == 0)
	{
		pwm_a_motor0 = (uint8_t)pwm_a;
		pwm_b_motor0 = (uint8_t)pwm_b;
		pwm_c_motor0 = (uint8_t)pwm_c;
	}

	if (motorNumber == 1)
	{
		pwm_a_motor1 = (uint8_t)pwm_a;
		pwm_b_motor1 = (uint8_t)pwm_b;
		pwm_c_motor1 = (uint8_t)pwm_c;
	}
}

void motorPowerOff() 
{
	/*Slår av power og setter farten/pos til 0*/
	MoveMotorPosSpeed(motorNumberPitch, 0, 0);
	MoveMotorPosSpeed(motorNumberYaw, 0, 0);
}

void moveInPos()
{

}

void motorPower()
{

}

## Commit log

2015-03-18 Added current Arduino build
    SAFF MEGA 2 is the current alpha release for the Arduino
2015-03-18 Pixy -> Brugi communication v0.1
    Should now be able to relay messages
2015-03-20 Arduino cleanup
    -Restructuring, moved power check to the main loop.
    -Main loop now replaces the mode spesific infinite while loops.
    -Big cleanup, removed surplus vars and reordered definitions
    -Brugi X-Y on RC now gets mapped before sending
    [SAFF-MEGA.ino]
2015-03-20 Bugfix
    Wake all serials, not just HW0
    [SAFF-MEGA.ino]
2015-03-23 Serial print now adheres to header
2015-03-23 Begun implementing aimbot serial in arduino
    Need to copy the serial header to arduino project directory, due to the
    fact that arduino refuse to accept links
2015-03-23 Serial header now contains RC mode
    Arduino has it implemented
2015-03-24 Aimbot serial reworked
    __ARDUINO is now replaced by __MEGA and __ESC
    [SAFF-MEGA.ino]
2015-03-26 Lots of changes
    to both serial and arduino mega code..
2015-03-27 Aimbot serial
    changed back to using hardwareserial pointer, created a template struct
    for common methods. implemented these changes in mega ino, but not in
    esc. coming soon
2015-03-27 Implemented new serial header in ESC ino
2015-03-30 Communication between devices
    is now fully operational.
2015-04-07 Mode select now updated
    -Mode select now only has 3 modes, to comply with ORX controller 3 mode
    switch
2015-04-09 Updated PC-serial settings
    -Now tested
    -Works
    -But after setup is called, buffer is out of sync somehow and sendx
    needs to be called about 3 times to get sync again. This will be fixed.
    [SAFF-MEGA.ino]
2015-04-13 Pixy serial fixes
    fixed bugs in
    -sync
    -update
    -vectors
    [proggreyshades.cpp]
2015-04-14 Updated MEGA for new power circuit
2015-04-14 Start in sleepMode and adapt new power circuit
2015-04-15 Esc fixes
2015-04-15 Esc fixes
    -limited YAW axis rotation
    -smoother RC movements
    [AimBot.ino, SAFF-MEGA.ino]
2015-04-17 Added: secure start and soft shutdown
    soft shutdown: kill all external modules for 1sec before powering down
    the arduino (prevents restart problem)
    secure start: externals off at startup
    [SAFF-MEGA.ino]
2015-04-17 Lots of pre-fullscale testing fixes
    [AimBot.ino, SAFF-MEGA.ino, proggreyshades.cpp]
2015-04-17 Pixy serial recieve bugfixing
    pixy can now handle incomming commands!
    ... or at least the first time.. known issue: pixy hangs after handling
    first command.
    [proggreyshades.cpp]
2015-04-18 Low-pass filter er nå justerbart
    Har også lagt til #define for MOTORPOWER og satt ned denne fra 255 til
    150.
    Etter utregninger har jeg endret filterstyrken på low-pass filteret, og
    heller satt ned SPEED_FACTOR til 10 for å kompansere for
    hastighetstapet.
2015-04-21 Pixy fixes
    - after sending a vector, pixy now waits for start command before doing
    anything else.
    [proggreyshades.cpp]
2015-04-22 Fullscale somewhat successfull
    Pixy tracking works, but rig is shaky. needs fixing.
    [AimBot.ino, SAFF-MEGA.ino]
2015-04-29 Removed power control from arduino
2015-04-29 more fine tuning of parameters
    reworked some of the logic behind the dc-motor controll aswell, wich
    significantly reduced rig shakyness.
    [AimBot.ino, SAFF-MEGA.ino, definitions.h]
2015-05-06 Desktop
    finaly a working program, so it's now time to look for bugs
    [SAFF-MEGA.ino]
2015-05-06 Revert "Desktop"
    This reverts commit a90e52917672ff9c5cbe50caa235be25e3aecf97.
    [SAFF-MEGA.ino]
2015-05-06 Revert "Revert "Desktop""
    This reverts commit 039f4dfedd6a7e6a44a728075ed89e88b8531ea2.
    [SAFF-MEGA.ino]
2015-05-06 ESC RC mode bugfix and MEGA timelapse added
    ESC RC mode bugfix( only one speed bug) and MEGA timelapse added
    [AimBot.ino, SAFF-MEGA.ino]
2015-05-06 Added a tester for MEGA to check PWM inputs
2015-05-07 Added ESC unit test
2015-05-08 Added array parser for ESC unit tester
2015-06-03 Added 3D models
    [5mm motorholder.SLDPRT, Assem2.SLDASM, Bunnplate til boks.SLDPRT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]
